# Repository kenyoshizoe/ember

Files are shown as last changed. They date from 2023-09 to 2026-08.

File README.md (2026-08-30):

# Ember
## Overview
32Key Hall Effect Keyboard for Gaming.

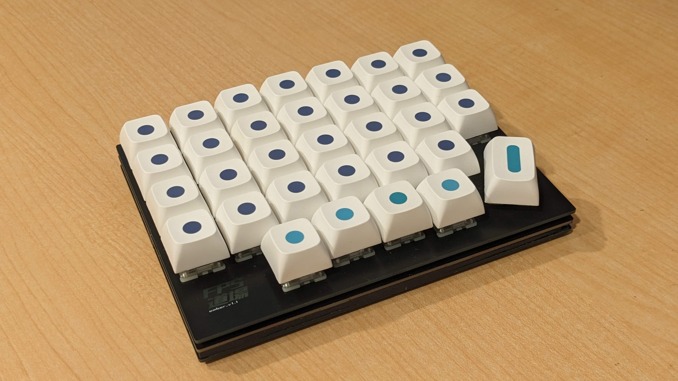
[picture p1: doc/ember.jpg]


## Web Configuration Tool
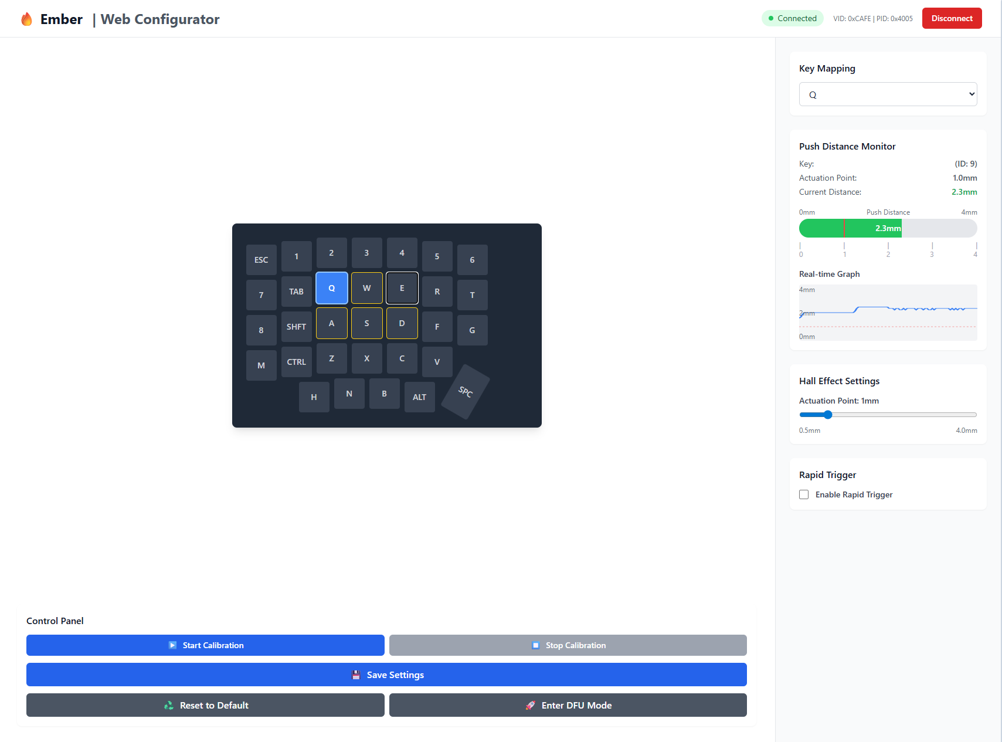
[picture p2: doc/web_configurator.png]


Meet Ember’s control room in the browser. The Next.js‑powered configurator lets you:

- Configuring keymaps with instant write-backs over Web Serial
- Watch real-time hall-effect telemetry and dial in rapid trigger thresholds
- Fire off calibration, DFU, and other maintenance commands in a single click

Launch (Chrome / Edge recommended):
https://ember.kenyo.dev

https://x.com/m3ssy_ken/status/1974076255810269626

## PCB
pcb/ember

基板はKiCAD7で制作され、USBコネクタを除く全てのパーツはJLCPCBのPCBAサービスで実装することができます。
TypeCコネクタは[5077CR-16-SMC2-BK-TR](https://akizukidenshi.com/catalog/g/gC-14356/)を用いることができます。

pcb was designed with KiCAD 7.
All of components except USB Connector is available at jlcpcb pcba service.

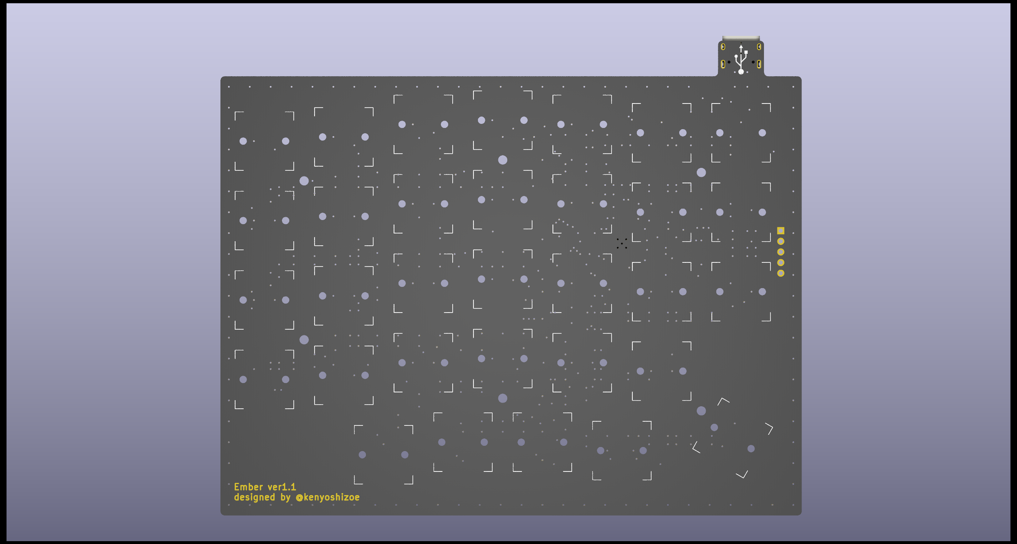
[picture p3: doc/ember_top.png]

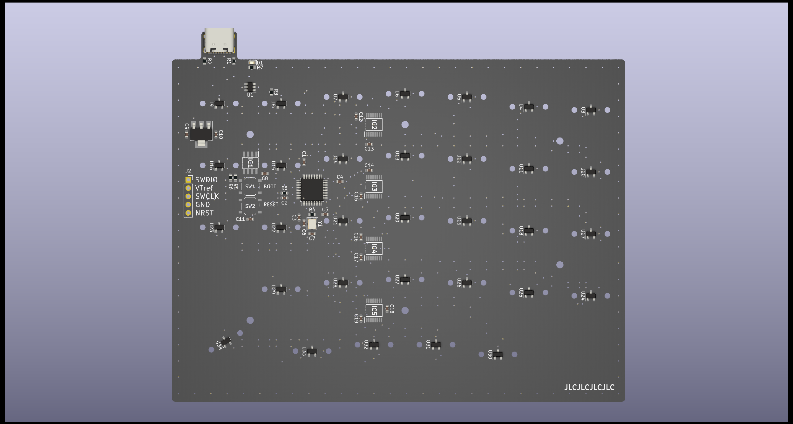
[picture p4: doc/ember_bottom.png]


## Case
pcb/ember_bottom_plate, pcb/ember_top_plate

## Communication
このキーボードはHID&CDC複合デバイスとして認識されます。
各種設定はCDCから行うことができます。

This keyboard is recognized as HID&CDC composite device.
Configuration (Keymapping, Calibration, Rapid Trigger, etc...) can be done from CDC.

### Packet Structure
Query (Read)
| Bytes | Description |
| --- | --- |
| 0x00 | 0 |
| 0x01~0x02 | Address |
| 0x03 | Length |

Response (Read)
| Bytes | Description |
| --- | --- |
| 0x00 | Success=0 Failed=1 |
| 0x01~0x02 | Address |
| 0x03 | Length |
| 0x04~(Length+4) | Data |

Query (Write)
| Bytes | Description |
| --- | --- |
| 0x00 | 1 |
| 0x01~0x02 | Address |
| 0x03 | Length |
| 0x04~(Length+4) | Data |

Response (Write)
| Bytes | Description |
| --- | --- |
| 0x00 | Success=0 Failed=1 |
| 0x01~0x02 | Address |
| 0x03 | Length |

これらのクエリ/レスポンスをCOBSを用いてエンコード/デコードしてから送受信します。
Send these query with encoding/decoding with COBS.

### Address Map
| Address | Description | W/R |
| --- | --- | --- |
| 0x0000-0x0004 | Key0 Config | W/R |
| 0x0005-0x0009 | Key1 Config | W/R |
| 0x000A-0x000E | Key2 Config | W/R |
| ... | ... | ... |
| 0x009B-0x009F | Key31 Config | W/R |
| 0x00A0-0x00FF | Reserved | - |
| 0x0100 | Key1 MIDI Note Number | W/R |
| 0x0101 | Key2 MIDI Note Number | W/R |
| 0x0102 | Key3 MIDI Note Number | W/R |
| ... | ... | ... |
| 0x0120-0x0FFF | Reserved | - |
| 0x1000-0x1003 | Key0 Calibaration Data | R |
| 0x1004-0x1007 | Key1 Calibaration Data | R |
| ... | ... | ... |
| 0x107B-0x107F | Key31 Calibration Data | R |
| 0x1080-0x1FFF | Reserved | - |
| 0x2000 | Key0 Push distance | R |
| 0x2001 | Key1 Push distance | R |
| ... | ... | ... |
| 0x201F | Key31 Push distance | R |
| 0x2020-0x2FFF | Reserved | - |
| 0x3000 | Save Config | W |
| 0x3001 | Calibration (0=Disable 1=Enable) | W |
| 0x3002 | Reset Config to default | W |
| 0x3003 | Reset MCU | W |
| 0x3004 | Enter DFU | W |
| 0x3005-0xFFFF | Reserved | - |
| 0x4000 | Mode (0=DISABLED, 1=CALIBRATE, 2=KEYBAORD, 3=MIDI) | W/R |

それぞれのキーの設定は次のようになっています。
Each key config is as follows:
| Address | Description |
| --- | --- |
| 0x00 | key_code |
| 0x01 | key_type (0=DISABLED, 1=CALIBRATE, 2=THRESHOLD, 3=RAPID_TRIGGER) |
| 0x02 | actuation_point (0.1mm unit) |
| 0x03 | rappid_trigger_up_sensivity |
| 0x04 | rappid_trigger_down_sensivity |

それぞれのキーのキャリブレーションデータは以下のようになっています。
Each key calibration data is as follows:
| Address | Description |
| --- | --- |
| 0x00~0x01 | max_value |
| 0x02~0x03 | min_value |

## License

Unless otherwise noted, all original content in this repository—including the
firmware, web configurator, scripts, PCB design files, schematics, and case
design files—is licensed under the [MIT License](LICENSE).

This includes permission to use the design files to manufacture, distribute,
and sell physical products based on those designs.

Third-party components remain subject to their respective licenses.

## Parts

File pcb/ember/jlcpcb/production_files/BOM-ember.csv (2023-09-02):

Comment | Designator | Footprint | LCSC
STM32F303CBTx | MCU1 | LQFP-48_7x7mm_P0.5mm | C108516
16MHz | Y1 | Crystal_SMD_3225-4Pin_3.2x2.5mm | C13738
100n | C1,C11,C12,C13,C14,C15,C16,C17,C18,C19,C2,C3,C4,C8 | C_0603_1608Metric | C14663
10p | C6,C7 | C_0603_1608Metric | C1634
10u | C9 | C_0603_1608Metric | C19702
1k | R4,R8 | R_0603_1608Metric | C21190
1.5k | R3 | R_0603_1608Metric | C22843
470 | R7 | R_0603_1608Metric | C23179
5.1k | R1,R2 | R_0603_1608Metric | C23186
10k | R5,R6 | R_0603_1608Metric | C25804
Hall_Sensor | U10,U11,U12,U13,U14,U15,U16,U17,U18,U19,U20,U21,U22,U23,U24,U25,U26,U27,U28,U29,U3,U30,U31,U32,U33,U34,U4,U5,U6,U7,U8,U9 | SOT-23 | C2904393
BOOT | SW1,SW2 | SW_Push_1P1T_XKB_TS-1187A | C318884
USB_C_Receptacle_USB2.0 | J1 | USB_C_Receptacle_XKB_U262-16XN-4BVC11 | C319148
ADG708BRUZ-REEL7 | IC2,IC3,IC4,IC5 | SOP65P640X120-16N | C35325
10n | C5 | C_0603_1608Metric | C57112
22u | C10 | C_0603_1608Metric | C59461
AMS1117-3.3 | U2 | SOT-223-3_TabPin2 | C6186
LED | D1 | LED_0603_1608Metric | C72043
M24C64-RMN6TP | IC1 | SOIC127P600X175-8N | C79988
SRV05-4 | U1 | SOT-23-6 | C85364
KeySwitch | H29 | MX-1U-NoPins
KeySwitch | H17 | MX-1U-NoPins
MountingHole | H3 | MountingHole_2.2mm_M2
KeySwitch | H20 | MX-1U-NoPins
MountingHole | H2 | MountingHole_2.2mm_M2
KeySwitch | H31 | MX-1U-NoPins
KeySwitch | H11 | MX-1U-NoPins
KeySwitch | H19 | MX-1U-NoPins
KeySwitch | H9 | MX-1U-NoPins
KeySwitch | H24 | MX-1U-NoPins
KeySwitch | H21 | MX-1U-NoPins
MountingHole | H1 | MountingHole_2.2mm_M2
KeySwitch | H23 | MX-1U-NoPins
KeySwitch | H10 | MX-1U-NoPins
KeySwitch | H14 | MX-1U-NoPins
KeySwitch | H32 | MX-1U-NoPins
MountingHole | H5 | MountingHole_2.2mm_M2
KeySwitch | H16 | MX-1U-NoPins
KeySwitch | H7 | MX-1U-NoPins
KeySwitch | H13 | MX-1U-NoPins
KeySwitch | H30 | MX-1U-NoPins
KeySwitch | H8 | MX-1U-NoPins
KeySwitch | H15 | MX-1U-NoPins
KeySwitch | H18 | MX-1U-NoPins
KeySwitch | H25 | MX-1U-NoPins
KeySwitch | H26 | MX-1U-NoPins
KeySwitch | H12 | MX-1U-NoPins
MountingHole | H6 | MountingHole_2.2mm_M2
KeySwitch | H27 | MX-1U-NoPins
KeySwitch | H28 | MX-1U-NoPins
MountingHole | H4 | MountingHole_2.2mm_M2
KeySwitch | H22 | MX-1U-NoPins
Conn_01x05_Socket | J2 | PinSocket_1x05_P2.54mm_Vertical
KeySwitch | H38 | MX-1U-NoPins
KeySwitch | H37 | MX-1U-NoPins
KeySwitch | H36 | MX-1U-NoPins
KeySwitch | H35 | MX-1U-NoPins
KeySwitch | H34 | MX-1U-NoPins
KeySwitch | H33 | MX-1U-NoPins

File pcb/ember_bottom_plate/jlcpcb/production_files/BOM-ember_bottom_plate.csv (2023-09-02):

Comment | Designator | Footprint | LCSC
MountingHole | H3 | MountingHole_2.2mm_M2
MountingHole | H1 | MountingHole_2.2mm_M2
MountingHole | H4 | MountingHole_2.2mm_M2
MountingHole | H2 | MountingHole_2.2mm_M2
MountingHole | H5 | MountingHole_2.2mm_M2
MountingHole | H6 | MountingHole_2.2mm_M2

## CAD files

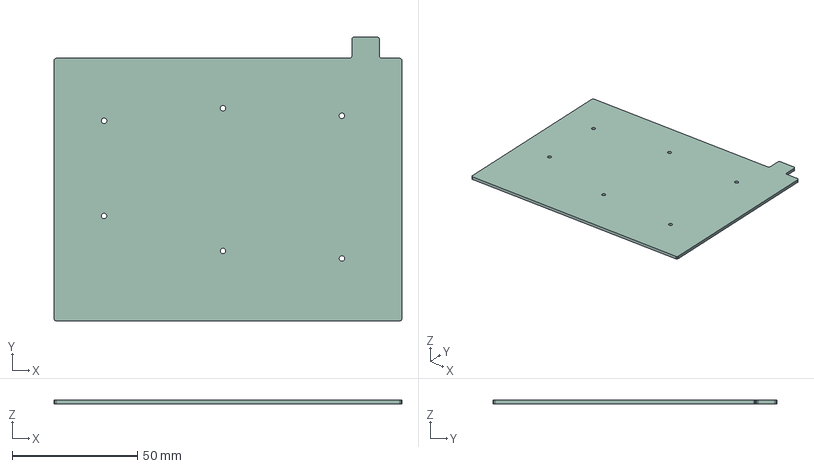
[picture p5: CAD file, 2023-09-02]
pcb/ember_bottom_plate/ember_bottom_plate.step
139.0 x 113.5 x 1.60 mm

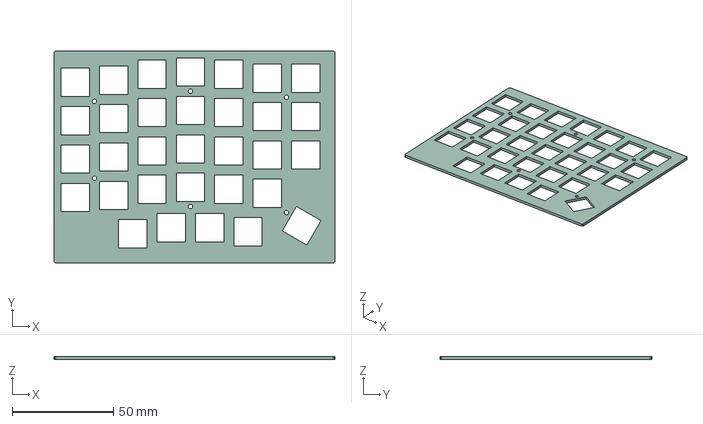
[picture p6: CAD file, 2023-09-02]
pcb/ember_top_plate/ember_top_plate.step
139.0 x 105.0 x 1.60 mm

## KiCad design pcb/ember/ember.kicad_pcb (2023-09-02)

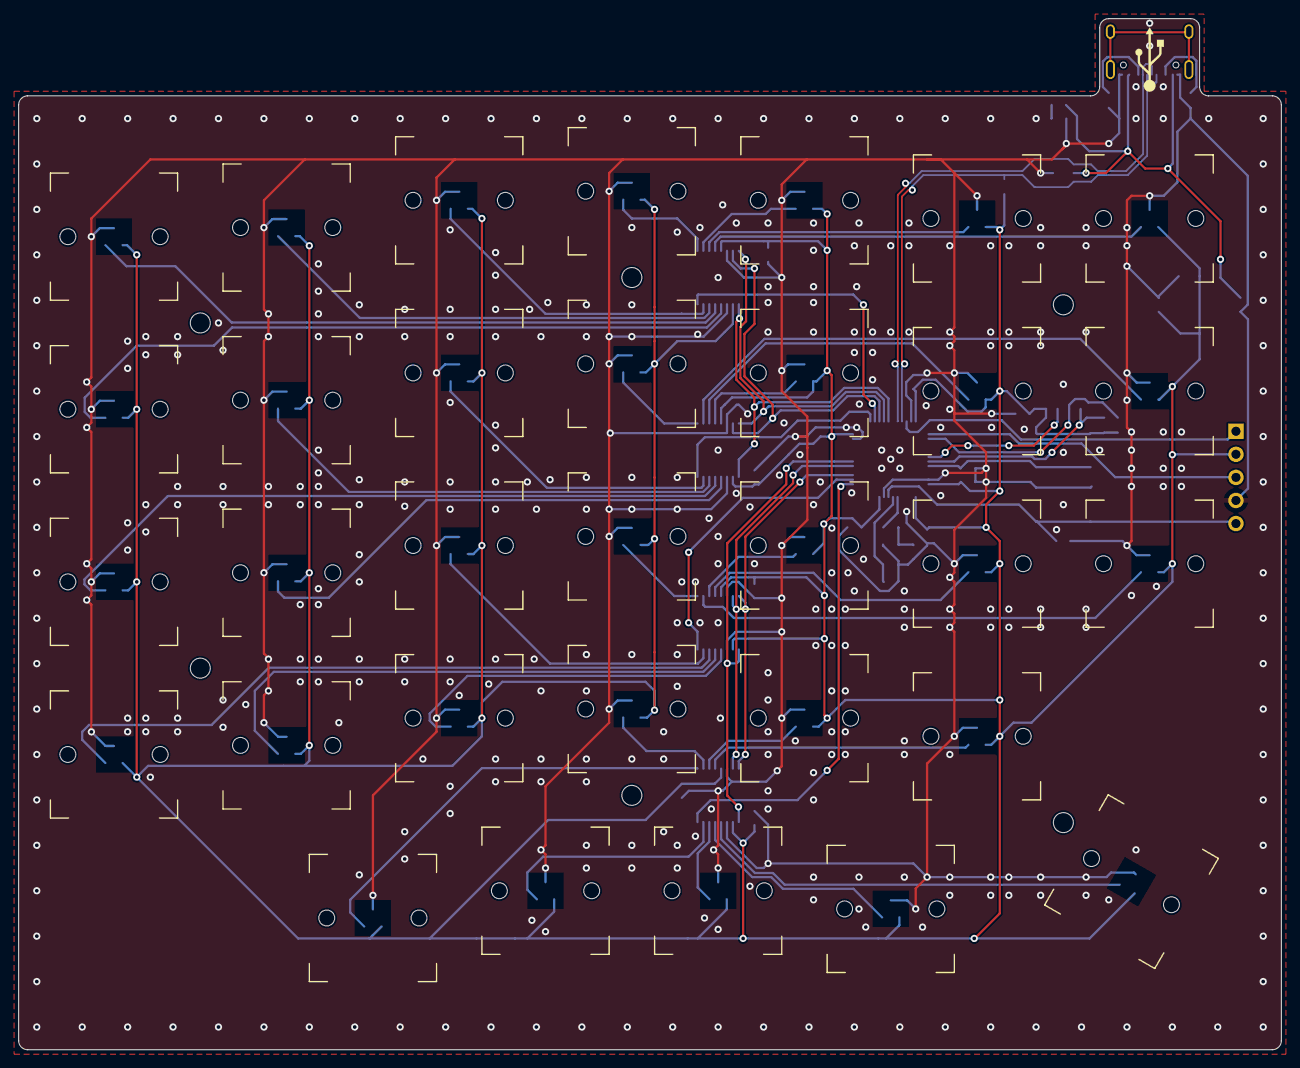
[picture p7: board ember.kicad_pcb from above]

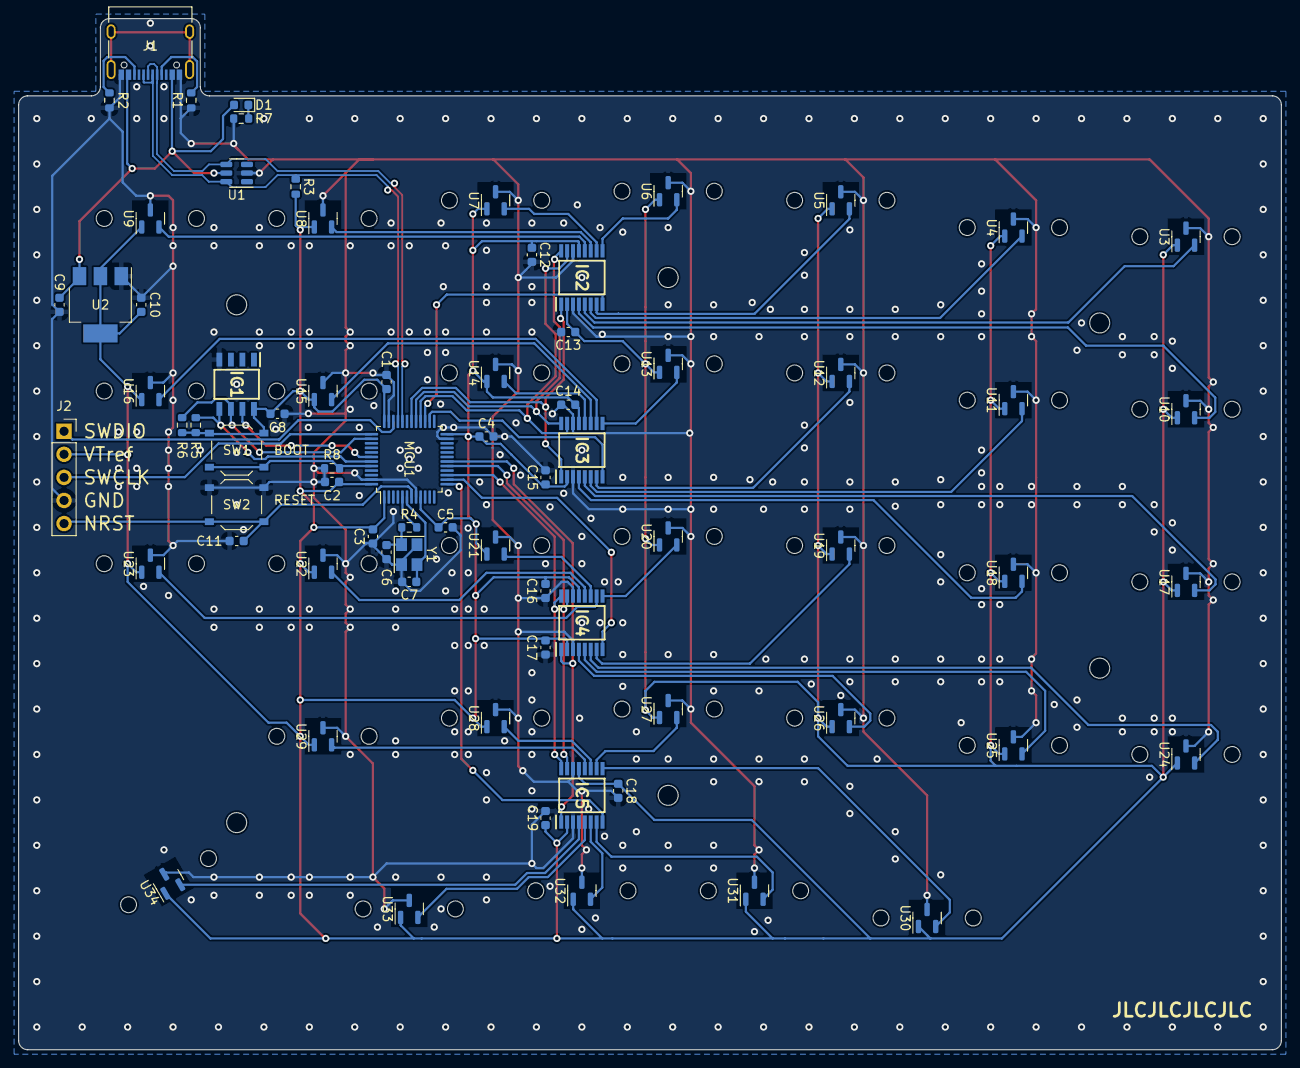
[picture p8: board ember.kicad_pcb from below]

Board: 2 copper layers, 139.0 x 113.5 mm, 111 parts (73 on the bottom side), 60 nets.

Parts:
C1, C2, C3, C4, C8, C11, C12, C13, C14, C15, C16, C17, C18, C19: 100n; C_0603_1608Metric
C5: 10n; C_0603_1608Metric
C6, C7: 10p; C_0603_1608Metric
C9: 10u; C_0603_1608Metric
C10: 22u; C_0603_1608Metric
D1: LED; LED_0603_1608Metric
H1, H2, H3, H4, H5, H6: MountingHole; MountingHole_2.2mm_M2
H7, H8, H9, H10, H11, H12, H13, H14, H15, H16, H17, H18, H19, H20, H21, H22, H23, H24, H25, H26, H27, H28, H29, H30, H31, H32, H33, H34, H35, H36, H37, H38: KeySwitch; MX-1U-NoPins
IC1: M24C64-RMN6TP; SOIC127P600X175-8N
IC2, IC3, IC4, IC5: ADG708BRUZ-REEL7; SOP65P640X120-16N
J1: USB_C_Receptacle_USB2.0; USB_C_Receptacle_XKB_U262-16XN-4BVC11
J2: Conn_01x05_Socket; PinSocket_1x05_P2.54mm_Vertical
MCU1: STM32F303CBTx; LQFP-48_7x7mm_P0.5mm
R1, R2: 5.1k; R_0603_1608Metric
R3: 1.5k; R_0603_1608Metric
R4, R8: 1k; R_0603_1608Metric
R5, R6: 10k; R_0603_1608Metric
R7: 470; R_0603_1608Metric
SW1: BOOT; SW_Push_1P1T_XKB_TS-1187A
SW2: RESET; SW_Push_1P1T_XKB_TS-1187A
U1: SRV05-4; SOT-23-6
U2: AMS1117-3.3; SOT-223-3_TabPin2
U3, U4, U5, U6, U7, U8, U9, U10, U11, U12, U13, U14, U15, U16, U17, U18, U19, U20, U21, U22, U23, U24, U25, U26, U27, U28, U29, U30, U31, U32, U33, U34: Hall_Sensor; SOT-23
Y1: 16MHz; Crystal_SMD_3225-4Pin_3.2x2.5mm

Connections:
+3.3V: C1.1, C2.1, C3.1, C4.1, C5.1, C8.1, C10.1, C12.1, C13.1, C14.1, C15.1, C16.1, C17.1, C18.1, C19.1, IC1.8 (VCC), IC2.2 (EN), IC2.13 (VDD), IC3.2 (EN), IC3.13 (VDD), IC4.2 (EN), IC4.13 (VDD), IC5.2 (EN), IC5.13 (VDD), J2.2, MCU1.1 (VBAT), MCU1.9 (VDDA), MCU1.24 (VDD), MCU1.36 (VDD), MCU1.48 (VDD), R3.2, R5.1, R6.1, SW1.2, U2.2 (VO), U3.1 (VDD), U4.1 (VDD), U5.1 (VDD), U6.1 (VDD), U7.1 (VDD), U8.1 (VDD), U9.1 (VDD), U10.1 (VDD), U11.1 (VDD), U12.1 (VDD), U13.1 (VDD), U14.1 (VDD), U15.1 (VDD), U16.1 (VDD), U17.1 (VDD), U18.1 (VDD), U19.1 (VDD), U20.1 (VDD), U21.1 (VDD), U22.1 (VDD), U23.1 (VDD), U24.1 (VDD), U25.1 (VDD), U26.1 (VDD), U27.1 (VDD), U28.1 (VDD), U29.1 (VDD), U30.1 (VDD), U31.1 (VDD), U32.1 (VDD), U33.1 (VDD), U34.1 (VDD)
+5V: C9.1, D1.2 (A), J1.A4 (VBUS), J1.A9 (VBUS), J1.B4 (VBUS), J1.B9 (VBUS), U1.5 (VP), U2.3 (VI)
ADC1: IC5.8 (D), MCU1.13 (PA3)
ADC2: IC4.8 (D), MCU1.14 (PA4)
ADC3: IC3.8 (D), MCU1.26 (PB13)
ADC4: IC2.8 (D), MCU1.27 (PB14)
BOOT: MCU1.44 (BOOT0), R8.1, SW1.1
GND: C1.2, C2.2, C3.2, C4.2, C5.2, C6.2, C7.2, C8.2, C9.2, C10.2, C11.2, C12.2, C13.2, C14.2, C15.2, C16.2, C17.2, C18.2, C19.2, IC1.4 (VSS), IC2.3 (VSS), IC2.14 (GND), IC3.3 (VSS), IC3.14 (GND), IC4.3 (VSS), IC4.14 (GND), IC5.3 (VSS), IC5.14 (GND), J1.A1 (GND), J1.A12 (GND), J1.B1 (GND), J1.B12 (GND), J2.4, MCU1.8 (VSSA), MCU1.23 (VSS), MCU1.35 (VSS), MCU1.47 (VSS), R1.2, R2.2, R7.2, R8.2, SW2.2, U1.2 (VN), U2.1 (GND), U3.3 (GND), U4.3 (GND), U5.3 (GND), U6.3 (GND), U7.3 (GND), U8.3 (GND), U9.3 (GND), U10.3 (GND), U11.3 (GND), U12.3 (GND), U13.3 (GND), U14.3 (GND), U15.3 (GND), U16.3 (GND), U17.3 (GND), U18.3 (GND), U19.3 (GND), U20.3 (GND), U21.3 (GND), U22.3 (GND), U23.3 (GND), U24.3 (GND), U25.3 (GND), U26.3 (GND), U27.3 (GND), U28.3 (GND), U29.3 (GND), U30.3 (GND), U31.3 (GND), U32.3 (GND), U33.3 (GND), U34.3 (GND), Y1.2, Y1.4
MUX1_A: IC4.1 (A0), IC5.1 (A0), MCU1.18 (PB0)
MUX1_B: IC4.16 (A1), IC5.16 (A1), MCU1.15 (PA5)
MUX1_C: IC4.15 (A2), IC5.15 (A2), MCU1.17 (PA7)
MUX2_A: IC2.1 (A0), IC3.1 (A0), MCU1.30 (PA9)
MUX2_B: IC2.16 (A1), IC3.16 (A1), MCU1.29 (PA8)
MUX2_C: IC2.15 (A2), IC3.15 (A2), MCU1.28 (PB15)
NRST: C11.1, J2.5, MCU1.7 (NRST), SW2.1
unnamed: C6.1, R4.1, Y1.1
unnamed: D1.1 (K), R7.1
unnamed: J1.A5 (CC1), R1.1
unnamed: J1.B5 (CC2), R2.1
RCC_OSC_IN: MCU1.5 (PF0), R4.2
RCC_OSC_OUT: C7.1, MCU1.6 (PF1), Y1.3
SCL: IC1.6 (SCL), MCU1.38 (PA15), R6.2
SDA: IC1.5 (SDA), MCU1.43 (PB7), R5.2
SENS_A_S1: IC2.4 (S1), U10.2 (OUT)
SENS_A_S2: IC2.5 (S2), U3.2 (OUT)
SENS_A_S3: IC2.6 (S3), U4.2 (OUT)
SENS_A_S4: IC2.7 (S4), U5.2 (OUT)
SENS_A_S5: IC2.12 (S5), U9.2 (OUT)
SENS_A_S6: IC2.11 (S6), U8.2 (OUT)
SENS_A_S7: IC2.10 (S7), U7.2 (OUT)
SENS_A_S8: IC2.9 (S8), U6.2 (OUT)
SENS_B_S1: IC3.4 (S1), U18.2 (OUT)
SENS_B_S2: IC3.5 (S2), U17.2 (OUT)
SENS_B_S3: IC3.6 (S3), U11.2 (OUT)
SENS_B_S4: IC3.7 (S4), U12.2 (OUT)
SENS_B_S5: IC3.12 (S5), U14.2 (OUT)
SENS_B_S6: IC3.11 (S6), U15.2 (OUT)
SENS_B_S7: IC3.10 (S7), U16.2 (OUT)
SENS_B_S8: IC3.9 (S8), U13.2 (OUT)
SENS_C_S1: IC4.4 (S1), U26.2 (OUT)
SENS_C_S2: IC4.5 (S2), U25.2 (OUT)
SENS_C_S3: IC4.6 (S3), U24.2 (OUT)
SENS_C_S4: IC4.7 (S4), U19.2 (OUT)
SENS_C_S5: IC4.12 (S5), U22.2 (OUT)
SENS_C_S6: IC4.11 (S6), U21.2 (OUT)
SENS_C_S7: IC4.10 (S7), U23.2 (OUT)
SENS_C_S8: IC4.9 (S8), U20.2 (OUT)
SENS_D_S1: IC5.4 (S1), U34.2 (OUT)
SENS_D_S2: IC5.5 (S2), U33.2 (OUT)
SENS_D_S3: IC5.6 (S3), U32.2 (OUT)
SENS_D_S4: IC5.7 (S4), U31.2 (OUT)
SENS_D_S5: IC5.12 (S5), U29.2 (OUT)
SENS_D_S6: IC5.11 (S6), U28.2 (OUT)
SENS_D_S7: IC5.10 (S7), U27.2 (OUT)
SENS_D_S8: IC5.9 (S8), U30.2 (OUT)
SWCLK: J2.3, MCU1.37 (PA14)
SWDIO: J2.1, MCU1.34 (PA13)
USB_D+: J1.A6 (D+), J1.B6 (D+), MCU1.33 (PA12), R3.1, U1.6 (IO4)
USB_D-: J1.A7 (D-), J1.B7 (D-), MCU1.32 (PA11), U1.4 (IO3)
WC: IC1.7 (~WC), MCU1.42 (PB6)

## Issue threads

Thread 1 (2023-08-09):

PCB design

kenyoshizoe, 2023-08-09:
とりあえず必要なのは
- MCU
- HoleSensor
- Analog Multiplexer

kenyoshizoe, 2023-08-09:
MCU:[STM32 F303CBT6](https://jlcpcb.com/partdetail/Stmicroelectronics-STM32F303CBT6/C108516)

kenyoshizoe, 2023-08-09:
Analog MultiplexerはBasic Partsという理由で[TI CD4051BM96](https://jlcpcb.com/partdetail/TexasInstruments-CD4051BM96/C21379)

Closed 2023-08-13.

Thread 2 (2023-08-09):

HallSensorの選定

kenyoshizoe, 2023-08-09:
#1

kenyoshizoe, 2023-08-09:
|sens|mv/GS(min)|mv/GS(typical)|mv/GS(max)|USD|
|---|---|---|---|---|
|[AH49E](https://jlcpcb.com/partdetail/DiodesIncorporated-AH49ENTRG1/C314698)|1.1|1.6|2.1|0.6951|
|[OH49E](https://jlcpcb.com/partdetail/Nanjing_OuzhuoTech-OH49ES/C85573)|1.8|2.0|2.2|0.2325|
|[SLSS49E](https://jlcpcb.com/partdetail/slkor_slkormicro_elec-SLSS49E3/C2904393)|2.25|2.5|2.75|0.1724|
|[ES49ESSO](https://jlcpcb.com/partdetail/Innosen-ES49ESSO/C2836204)|1.8|2.2|2.6|0.2428|
|[GH39FKSW](https://jlcpcb.com/partdetail/Gochip_Elec_Tech_shanghai-GH39FKSW/C266230)|1.45|1.8|2.0|0.1284|

GH39FKSWはJLCには在庫なし

kenyoshizoe, 2023-08-09:
[先駆者](https://twitter.com/sivaemon/status/1686400747469201409)によるとAH49E 3.3Vで1.6V~0.96Vらしいのでtypicalの値である1.6mv/GSと仮定すると
```
(3.3/2-1.6)/1.6*1000=31.25[GS]
(3.3/2-0.96)/1.6*1000=431.25[GS]
```

kenyoshizoe, 2023-08-09:
[gateron ks-20](https://gateron.com/products/gateron-ks-20-magnetic-white-switch-set?VariantsId=10690)は102GS~905GSらしい

Closed 2023-08-13.

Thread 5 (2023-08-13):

ケース設計

kenyoshizoe, 2023-08-13:

kenyoshizoe, 2023-08-13:
とりあえずアルミ板金

kenyoshizoe, 2023-08-15:
ガスケットマウントでやりたい気持ちが出てきた
上から
t2アルミ
t5アクリル
t8アクリル
t2アルミ
みたいにしてt5アクリルのところに1.5mm poron、t1.5アルミプレート、3mm pronを突っ込むと
(5-1.5)/(1.5+3)=0.78で22%くらいの圧縮率になる

kenyoshizoe, 2023-08-25:
キーと基板がほぼ固定されないのでプレートだけ固定するのだとNG
プレートと基板を繋ぐ必要がある

kenyoshizoe, 2023-08-27:
全体
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
ガスケット部断面
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
TypeCコネクタ部分
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

kenyoshizoe, 2023-08-27:
プレートと基板は普通に低頭M2ネジ+ナットでいく

kenyoshizoe, 2023-08-27:
若干調整

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

kenyoshizoe, 2023-08-28:
ええやん

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

kenyoshizoe, 2023-08-28:
t8のアクリル切れるか確認して行けるならアクリル発注する

kenyoshizoe, 2023-09-02:
流石に↑を複数作るのはしんどいのでサンドイッチマウントタイプも設計した
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

kenyoshizoe, 2023-09-16:
一旦close
サンドイッチマウントとか外注3dプリント製とかでやりたくなったらそれはその時で、

Closed 2023-09-16.

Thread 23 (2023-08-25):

ADCで読む前にOPAMPに通す

kenyoshizoe, 2023-08-25:
スケーリングしたほうが良さそう

kenyoshizoe, 2023-08-26:
個体差で読み取り最大値がすでに2048超えているのがあるので2倍するとあれかもしれん...

```
00> Key 0: 1913 1039
00> Key 1: 1766 1059
00> Key 2: 2033 1274
00> Key 3: 1677 1094
00> Key 4: 2184 1257
00> Key 5: 1985 1130
00> Key 6: 2162 1117
00> Key 7: 1542 1018
00> Key 8: 2090 1140
00> Key 9: 2071 1232
00> Key 10: 1999 1164
00> Key 11: 2027 1131
00> Key 12: 1585 1023
00> Key 13: 1718 1025
00> Key 14: 1827 1029
00> Key 15: 2014 1444
00> Key 16: 2249 1566
00> Key 17: 1882 1288
00> Key 18: 1787 1120
00> Key 19: 1811 1079
00> Key 20: 1891 1056
00> Key 21: 1792 1022
00> Key 22: 1843 1117
00> Key 23: 1823 1117
00> Key 24: 1819 1138
00> Key 25: 1841 1071
00> Key 26: 2045 1063
00> Key 27: 1775 1133
00> Key 28: 2196 1517
00> Key 29: 2030 1304
00> Key 30: 1892 1173
00> Key 31: 1774 1012
```

Closed 2023-08-26.

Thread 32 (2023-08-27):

低オン抵抗のAnalog Muxに変更する

kenyoshizoe, 2023-08-27:
現状内部ADCのコンデンサに充電するまで181Cycle@48Mhzつまり3.78usくらいかかってる。
多分原因はAnalogMuxのON抵抗が高いこと。

今使ってるのは[TI CD4052BM96](https://jlcpcb.com/partdetail/TexasInstruments-CD4052BM96/C6521)でON抵抗470ohmくらい。
[AnalogDevices ADG708BRUZ-REEL7](https://jlcpcb.com/partdetail/AnalogDevices-ADG708BRUZREEL7/C35325)(4.5ohm)とかのON抵抗が低いものを使えば多少改善しそう。

kenyoshizoe, 2023-08-27:
（もちろんコストも0.28USDから1.99USD+Extended Feeに跳ね上がるけど）

kenyoshizoe, 2023-08-27:
75ohmで0.4USD+Extended Fee

https://jlcpcb.com/partdetail/TexasInstruments-SN74LV4051ATDRQ1/C2673147

kenyoshizoe, 2023-08-27:
4ohm 3.5USD

https://jlcpcb.com/partdetail/TexasInstruments-TMUX1108PWR/C1021800

kenyoshizoe, 2023-08-27:
## Analog Devices
ADG708
3ohm 1.99USD
https://jlcpcb.com/partdetail/AnalogDevices-ADG708BRUZREEL7/C35325

MAX4638
2.5ohm 2.31USD
https://jlcpcb.com/partdetail/48068-MAX4638EUET/C47063

ADG1608
4.5ohm 4.42USD
https://jlcpcb.com/partdetail/AnalogDevices-ADG1608BRUZREEL7/C579034

kenyoshizoe, 2023-08-27:
ADG708が良さそうな雰囲気

Closed 2023-08-28.

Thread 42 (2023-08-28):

Hallsens Linearlization

kenyoshizoe, 2023-08-28:
どうやら押し込み量：出力電圧は線形にはなってないっぽい...
LookUpTableなりなんなりを生成してADCの値→距離に変換する方法を真面目に考える必要がある

kenyoshizoe, 2023-09-02:
ノギスでスイッチを押し込みながら出力値のデータ取った

|押し込み量 | ADC | 1901-ADC |
| --- | --- | --- |
|0 | 1900 | 1|
|0.4 | 1850 | 51|
|0.8 | 1820 | 81|
|1.2 | 1785 | 116|
|1.6 | 1725 | 176|
|2 | 1655 | 246|
|2.4 | 1530 | 371|
|2.8 | 1390 | 511|
|3.2 | 1200 | 701|
|3.6 | 1070 | 831|
|3.8 | 1046 | 855|

kenyoshizoe, 2023-09-02:
プロットするとこんな感じでlogスケールを取ればだいたい線形になることがわかった

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

kenyoshizoe, 2023-09-02:
x:=押し込み量
y:=出力最大値-出力値
の関係が

$$
y=a(e^{bx}-1) \space (b:=log(y_max/a+1)/4))
$$

で表されると仮定し、
↓のスクリプトで適当にaのフィッティングを行ったところ

```python
import matplotlib.pyplot as plt
import numpy as np
import math

a = 200
b = math.log(855 / a + 1) / 4

x = np.arange(0, 4, 0.01)
y = a * (np.exp(b * x) - 1)

plt.xlabel('travel')
plt.ylabel('adc value')
plt.plot(x, y)

x1 = np.array([0, 0.4, 0.8, 1.2, 1.6, 2.0, 2.4, 2.8, 3.2, 3.6, 4])
y1 = np.array([1, 51, 81, 116, 176, 246, 371, 511, 701, 831, 855])
plt.plot(x1, y1, 'ro')

plt.savefig('ember.png')
```

a=200くらいが良さそうとなったのでaをハードコーディングする形で実装した。

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

Closed 2023-09-02.

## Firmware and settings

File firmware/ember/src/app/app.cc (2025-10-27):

#include "ember/app/app.h"

#include "SEGGER_RTT.h"
#include "ember/commnication/configrator.h"
#include "ember/keyboard/config.h"
#include "ember/keyboard/keyboard.h"
#include "ember/module/cd4051b.h"
#include "ember/module/flash.h"

// Keyboard
ember::Keyboard* keyboard;
// Config
ember::Config config;
// Modules
ember::CD4051B amux1(MUX1_A_GPIO_Port, MUX1_A_Pin, MUX1_B_GPIO_Port, MUX1_B_Pin,
                     MUX1_C_GPIO_Port, MUX1_C_Pin);
ember::CD4051B amux2(MUX2_A_GPIO_Port, MUX2_A_Pin, MUX2_B_GPIO_Port, MUX2_B_Pin,
                     MUX2_C_GPIO_Port, MUX2_C_Pin);

// Variables for DMA ADC
uint16_t adc_val[4];
bool adc12_running = false;
bool adc34_running = false;

uint8_t switchToBootloader __attribute__((section(".noinit")));

void usb_bootloader_init() {
  // Check if we need to jump to the bootloader
  if (switchToBootloader == 0x11) {
    void (*SysMemBootJump)(void);
    switchToBootloader = 0x00;
    volatile uint32_t addr = 0x1FFFD800;
    SysMemBootJump = (void (*)(void))(*((uint32_t*)(addr + 4)));
    HAL_RCC_DeInit();   // Reset the system clock
    SysTick->CTRL = 0;  // Reset the  SysTick Timer
    SysTick->LOAD = 0;
    SysTick->VAL = 0;
    __set_MSP(*(uint32_t*)addr);  // Set the Main Stack Pointer
    SysMemBootJump();
    while (1);
  }
}

void setup() {
  SEGGER_RTT_Init();
  // Load Config
  bool load_success = ember::Flash::LoadConfig(config);
  if (!load_success) {
    config.mode = ember::Config::Mode::DISABLED;
  }
  keyboard = new ember::Keyboard(config);
  // Start Calibrate at first time
  // Init modules
  amux1.Init();
  amux2.Init();
  // Start ADC
  HAL_ADC_Start(&hadc1);
  HAL_ADC_Start(&hadc2);
  HAL_ADC_Start(&hadc3);
  HAL_ADC_Start(&hadc4);
  adc12_running = true;
  HAL_ADCEx_MultiModeStart_DMA(&hadc1, reinterpret_cast<uint32_t*>(adc_val), 1);
  adc34_running = true;
  HAL_ADCEx_MultiModeStart_DMA(&hadc3, reinterpret_cast<uint32_t*>(adc_val + 2),
                               1);
  // TinyUSB init

  tusb_rhport_init_t dev_init = {.role = TUSB_ROLE_DEVICE,
                                 .speed = TUSB_SPEED_AUTO};
  tusb_init(0, &dev_init);  // initialize device stack on roothub port 0

  // Start Timer
  HAL_TIM_Base_Start_IT(&htim17);
  // Start Configurator
  ember::Configurator::GetInstance()->SetKeyboard(keyboard);
  ember::Configurator::GetInstance()->SetConfig(&config);
  ember::Configurator::GetInstance()->Init();

  SEGGER_RTT_printf(0, "Ember startup.\n");
}

void loop() { tud_task(); }

void HAL_TIM_PeriodElapsedCallback(TIM_HandleTypeDef* htim) {
  // 250Hz
  if (htim == &htim17) {
    if (adc12_running || adc34_running) {
      SEGGER_RTT_printf(0, "ADC is running\n");
      return;
    }

    keyboard->Update();

    adc12_running = true;
    HAL_ADCEx_MultiModeStart_DMA(&hadc1, reinterpret_cast<uint32_t*>(adc_val),
                                 1);
    adc34_running = true;
    HAL_ADCEx_MultiModeStart_DMA(&hadc3,
                                 reinterpret_cast<uint32_t*>(adc_val + 2), 1);
    return;
  }
}

void HAL_ADC_ConvCpltCallback(ADC_HandleTypeDef* hadc) {
  if (hadc != &hadc1 && hadc != &hadc3) {
    return;
  }

  // Check both ADCs are completed
  if (hadc == &hadc1) {
    keyboard->SetADCValue(0, amux1.GetCh(), adc_val[0]);
    keyboard->SetADCValue(1, amux1.GetCh(), adc_val[1]);
    amux1.NextCh();
    if (amux1.GetCh() == 0) {
      adc12_running = false;
      return;
    }
    HAL_ADCEx_MultiModeStart_DMA(&hadc1, reinterpret_cast<uint32_t*>(adc_val),
                                 1);
  }
  if (hadc == &hadc3) {
    keyboard->SetADCValue(2, amux2.GetCh(), adc_val[2]);
    keyboard->SetADCValue(3, amux2.GetCh(), adc_val[3]);
    amux2.NextCh();
    if (amux2.GetCh() == 0) {
      adc34_running = false;
      return;
    }
    HAL_ADCEx_MultiModeStart_DMA(&hadc3,
                                 reinterpret_cast<uint32_t*>(adc_val + 2), 1);
  }
}

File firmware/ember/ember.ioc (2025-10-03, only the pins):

Mcu.UserName=STM32F303CBTx
PA11.Signal=USB_DM
PA12.Signal=USB_DP
PA13.Signal=SYS_JTMS-SWDIO
PA14.Signal=SYS_JTCK-SWCLK
PA15.Signal=I2C1_SCL
PA3.Signal=ADC1_IN4
PA4.Signal=ADC2_IN1
PA5.GPIO_Label=MUX1_B
PA5.Signal=GPIO_Output
PA7.GPIO_Label=MUX1_C
PA7.Signal=GPIO_Output
PA8.GPIO_Label=MUX2_B
PA8.Signal=GPIO_Output
PA9.GPIO_Label=MUX2_A
PA9.Signal=GPIO_Output
PB0.GPIO_Label=MUX1_A
PB0.Signal=GPIO_Output
PB13.Signal=ADC3_IN5
PB14.Signal=ADC4_IN4
PB15.GPIO_Label=MUX2_C
PB15.Signal=GPIO_Output
PB6.GPIO_Label=EEPROM_WC
PB6.Signal=GPIO_Output
PB7.Signal=I2C1_SDA
PF0-OSC_IN.Signal=RCC_OSC_IN
PF1-OSC_OUT.Signal=RCC_OSC_OUT

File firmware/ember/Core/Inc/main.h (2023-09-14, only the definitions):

#define MUX1_B_Pin GPIO_PIN_5
#define MUX1_B_GPIO_Port GPIOA
#define MUX1_C_Pin GPIO_PIN_7
#define MUX1_C_GPIO_Port GPIOA
#define MUX1_A_Pin GPIO_PIN_0
#define MUX1_A_GPIO_Port GPIOB
#define MUX2_C_Pin GPIO_PIN_15
#define MUX2_C_GPIO_Port GPIOB
#define MUX2_B_Pin GPIO_PIN_8
#define MUX2_B_GPIO_Port GPIOA
#define MUX2_A_Pin GPIO_PIN_9
#define MUX2_A_GPIO_Port GPIOA
#define EEPROM_WC_Pin GPIO_PIN_6
#define EEPROM_WC_GPIO_Port GPIOB

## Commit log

2023-08-13 :tada: add pcb design
    [BOM-ember.csv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]
2023-08-13 :wrench: add .gitignore for kicad
2023-08-14 :bug: fix cb4051b ch_
    [cd4051b.cc]
2023-08-14 :wrench: change adc settings
2023-08-23 :wrench: ver1.1
    [ember.kicad_pcb, ember.kicad_sch, hallsens.kicad_sch]
2023-08-23 :sparkles: add eeprom
    [ember.kicad_pcb, ember.kicad_sch, hallsens.kicad_sch]
2023-08-24 :bug: add 1.5k pullup to D+
    [ember.kicad_pcb, ember.kicad_sch]
2023-08-24 :wrench: add VTref Pin
    [ember.kicad_pcb, ember.kicad_sch]
2023-08-25 :sparkles: all key adc
2023-08-25 :sparkles: adc all kyes @ 800Hz
2023-08-26 :sparkles: change adc sampling time
2023-08-27 change hall size 3.5mm→2.2mm(M2)
    [ember.kicad_pcb, ember.kicad_sch]
2023-08-27 :sparkles: change usb connector position
    [ember.kicad_pcb]
2023-08-28 :sparkles: replace cd4052->ad708
    [ember.kicad_pcb, ember.kicad_sch, hallsens.kicad_sch]
2023-08-28 :sparkles: add 3d data
    [ember.kicad_pcb]
2023-08-28 :sparkles: add bypass cap
    [ember.kicad_pcb, ember.kicad_sch, hallsens.kicad_sch]
2023-08-29 :sparkles: change end calibration process
2023-08-29 :wastebasket: reduce setup print
2023-08-31 :sparkles: opampを使ってのADCに切り替えられるようにピンアサインを変更
    [ember.kicad_pcb, ember.kicad_sch, hallsens.kicad_sch]
2023-09-02 :sparkles: add pcb plates
    [BOM-ember_bottom_plate.csv, BOM-ember_top_plate.csv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]
2023-09-02 :sparkles: add usb logo
    [ember.kicad_pcb]
2023-09-02 :sparkles: export production files
    [BOM-ember.csv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]
2023-09-13 :wrench: change cubemx pin assign
2023-09-13 :rocket: polling rate 500Hz
2023-09-16 :bug: fix Keyboard::Keyboard constructor
    [keyboard.cc]
2023-09-16 :memo: add pcb images to readme
2023-09-27 🔧 introducing prettier
2023-09-27 🔧 Add .prettierignore
2023-09-27 🎨 applied formatter
2023-09-27 🔧 modified config file
2023-09-27 ⚰️ removed codes and a file no longer needed
2023-09-27 🌱 update html metadata
2023-09-27 🔥 removed files and codes no longer needed
2023-09-27 🔥 removed codes no longer needed.
2023-09-27 💄 add a temporary UI for Configurator
2025-10-03 :sparkles: add button to enter-dfu
2025-10-04 :tada: add DisabledKey, CalibratingKey, Velocity Calucuration, MIDI Mode
2025-10-04 :bug: fix configurator length
    [flash.cc]
2025-10-04 :bug: add blank 3bytes to Config for alignment
    [config.h]
2026-02-12 Update README with tweet link and PCB details
    Added a link to a tweet and updated PCB information.
2026-02-28 :bug: fix Rapid Trigger config not loaded correctly from device
    Reading keyType was comparing against 1 (CALIBRATE) instead of 3 (RAPID_TRIGGER),
    causing Rapid Trigger to always appear disabled when reloading the UI.

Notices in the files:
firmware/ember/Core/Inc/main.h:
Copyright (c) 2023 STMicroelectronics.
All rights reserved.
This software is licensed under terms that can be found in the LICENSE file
